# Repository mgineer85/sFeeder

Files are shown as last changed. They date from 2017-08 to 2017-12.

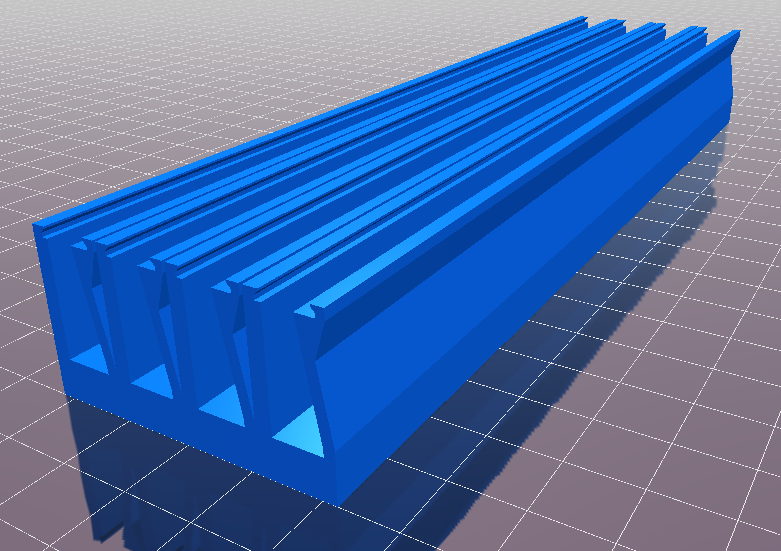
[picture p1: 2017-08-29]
parametric_feeder_example.png

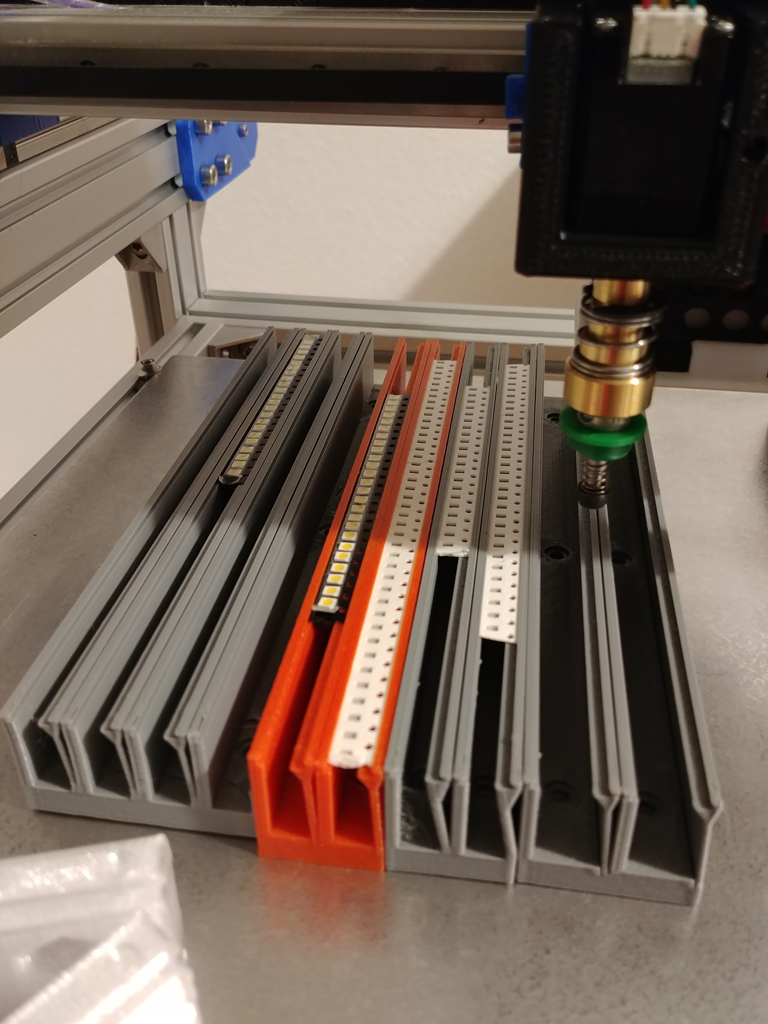
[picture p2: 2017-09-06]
parametric_feeder_photo.jpg

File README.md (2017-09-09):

# Parametric SMT Tape Feeder
=====

What is it for?
---
Serves to hold SMT tapes with resistors, capacitors, etc. in place. Designed to use in a Pick and Place Machine, like [OpenPnP](http://openpnp.org/). Another option would be [this](http://malte-randt.de/strip-feeders-and-modular-tray-for-smd/).

Features
---
  * parametric design fully adaptable to your needs
  * width of one feeder is tapeWidth + 3mm, eg. for 8mm tapes the feeder will be 11mm 
  * gang multiple feeder in one element
  * fully 3d printable, optimized design for best print results
  * keeps tape in position by slight force causing friction
  * no vitamins needed
  * prepared to be mounted to bed by 6mmx3mm magnets or M3 screw
  * try in Thingiverse Customizer

https://www.thingiverse.com/thing:2506053

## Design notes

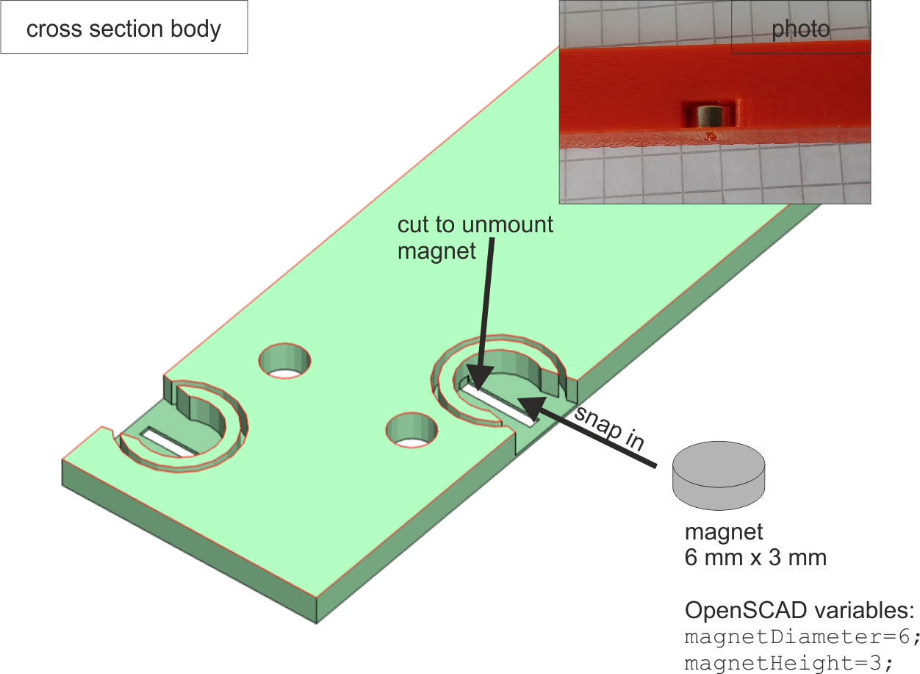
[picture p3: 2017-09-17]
sFeederOpenSCAD_magnetPockets.png

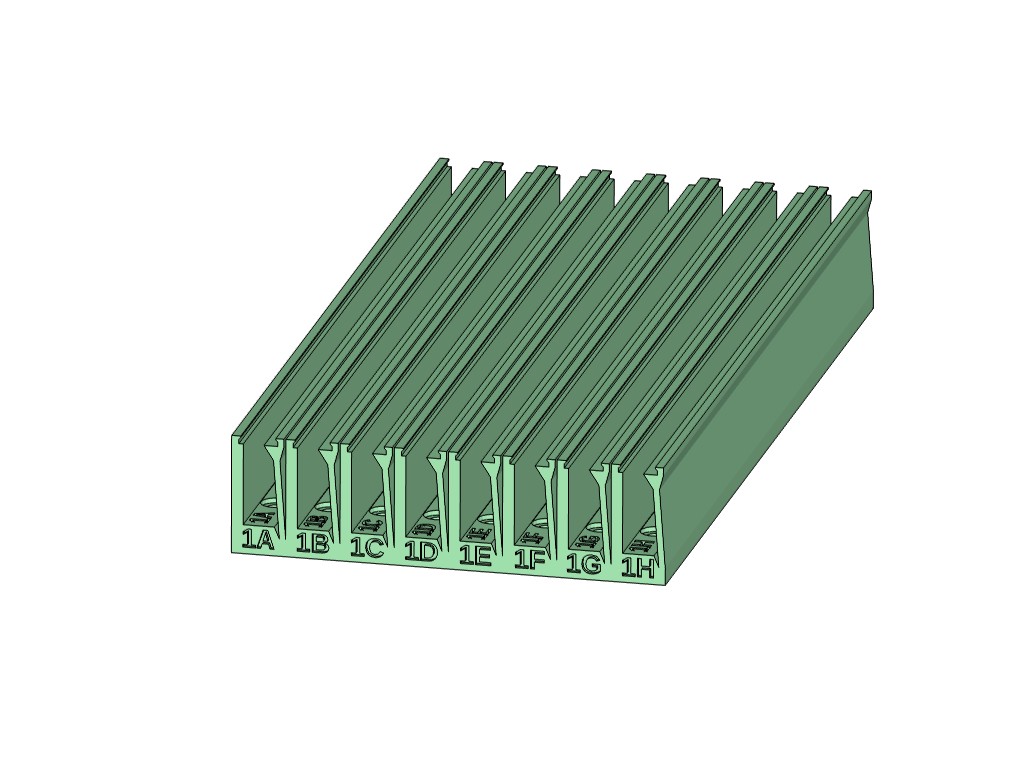
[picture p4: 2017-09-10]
gangedFeeder8mm with Identifier.jpg

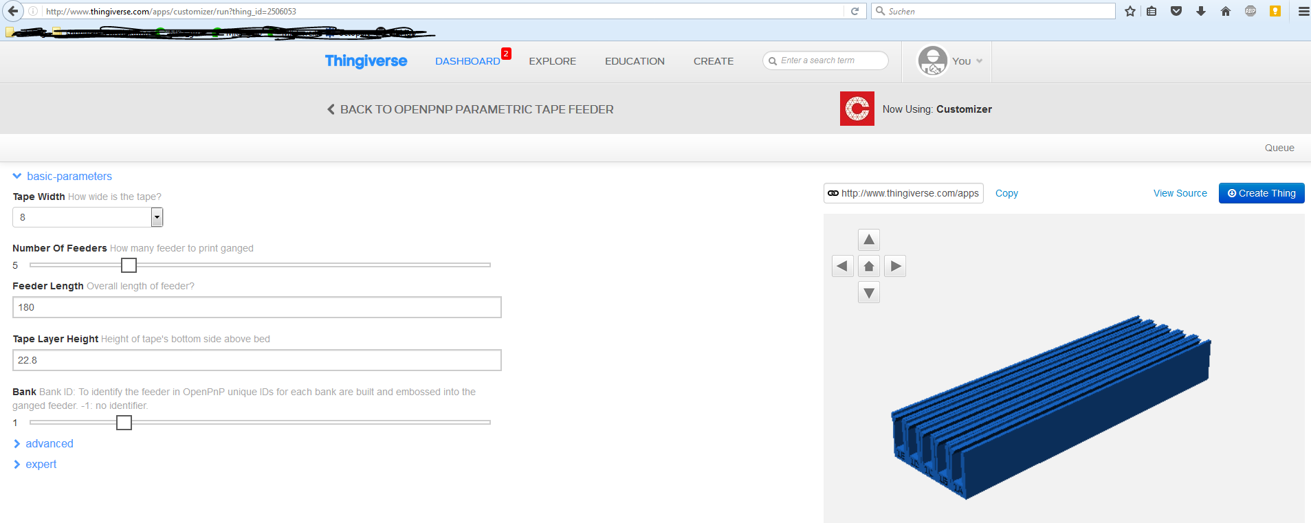
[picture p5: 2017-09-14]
screenshot_customizer.PNG

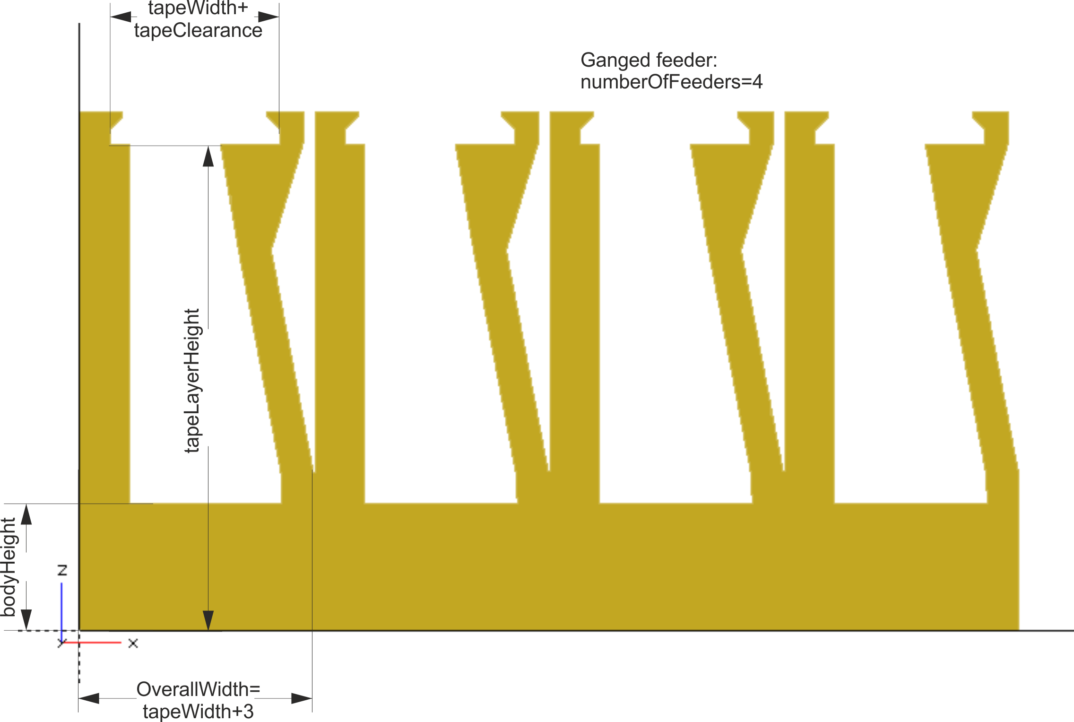
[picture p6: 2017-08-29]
parametric_feeder_desc.png

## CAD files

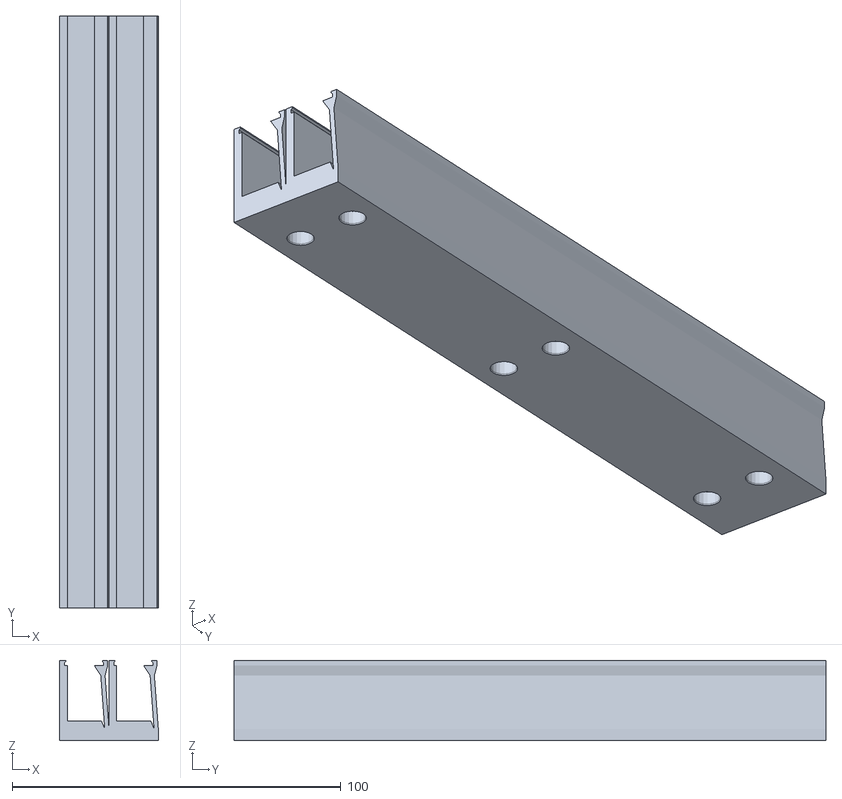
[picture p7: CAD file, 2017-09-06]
sFeeder_12mm_2feeders_180mm_22.8mm.stl
30.0 x 180.0 x 24.4

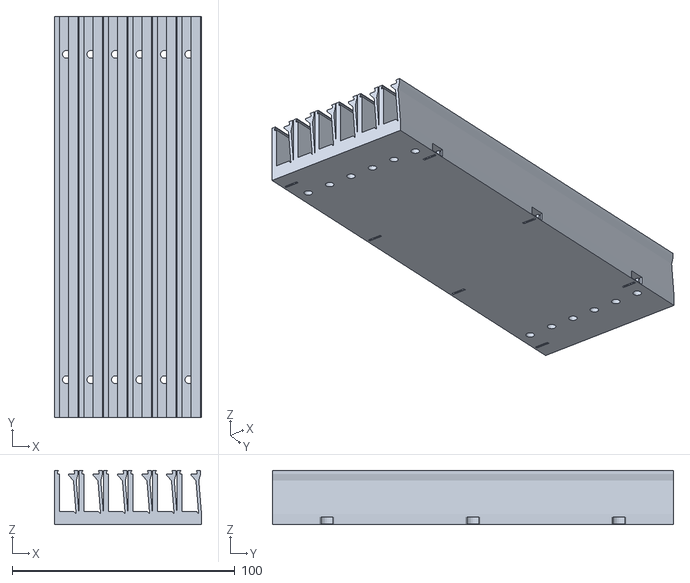
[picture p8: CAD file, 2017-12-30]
stl/sFeeder_8mm_6ganged.stl
66.0 x 180.0 x 24.4

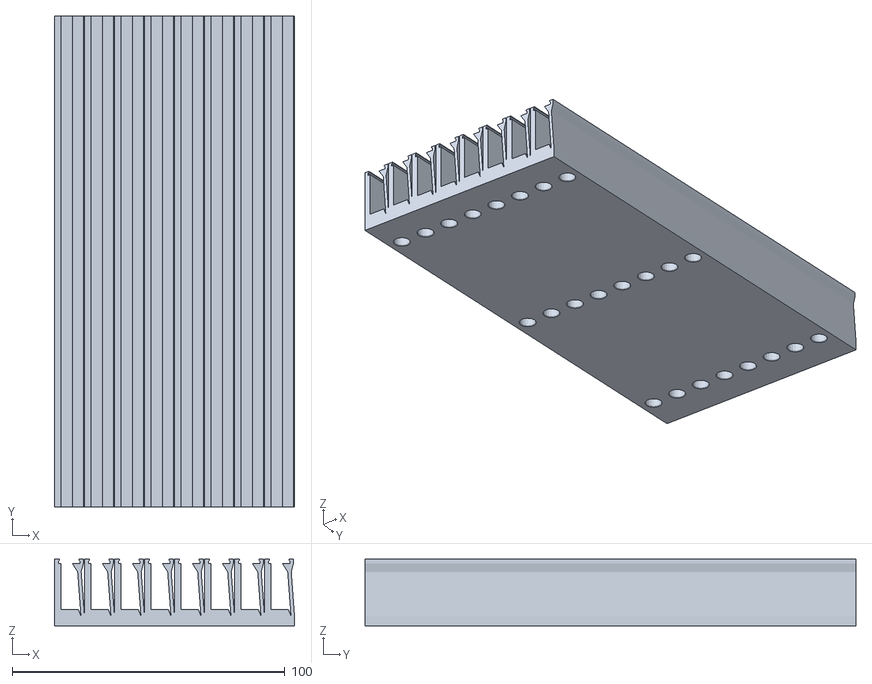
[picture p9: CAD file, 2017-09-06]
sFeeder_8mm_8feeders_180mm_22.8mm.stl
88.0 x 180.0 x 24.4

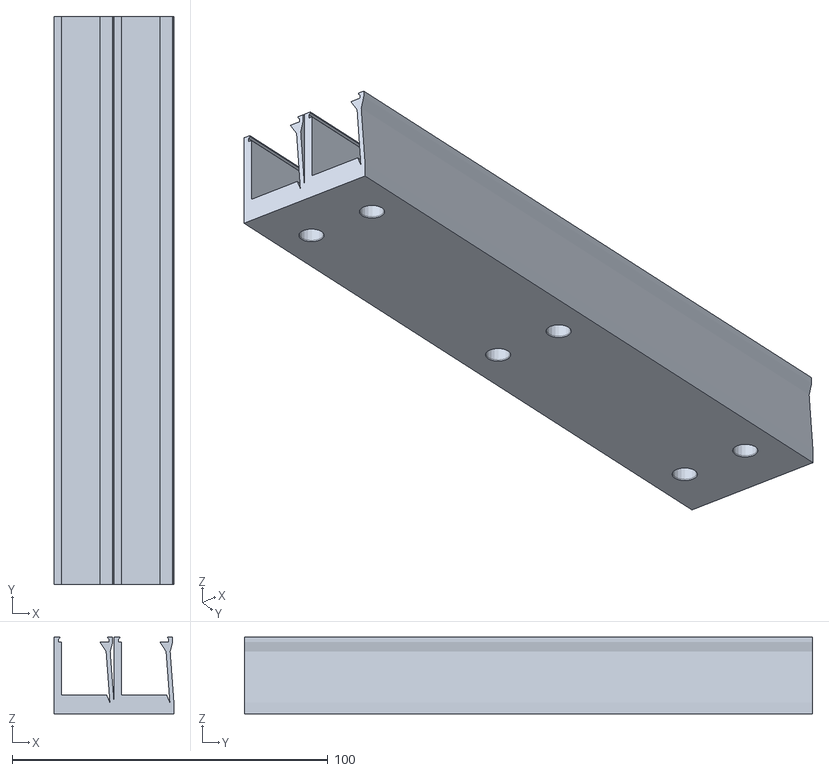
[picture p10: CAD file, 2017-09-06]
sFeeder_16mm_2feeders_180mm_22.8mm.stl
38.0 x 180.0 x 24.4

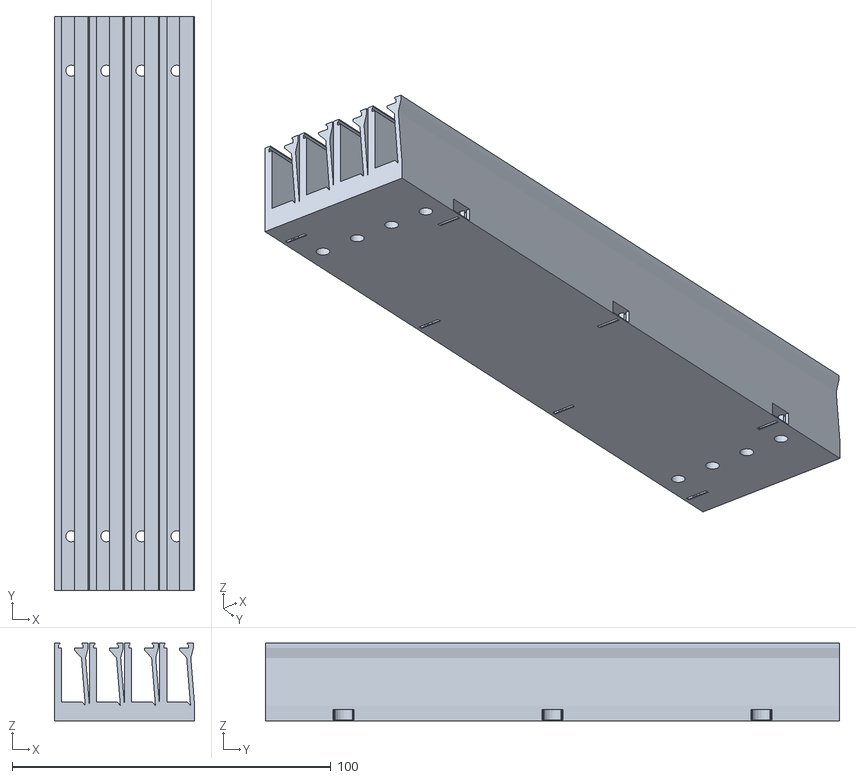
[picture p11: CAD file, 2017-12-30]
stl/sFeeder_8mm_4ganged.stl
44.0 x 180.0 x 24.4

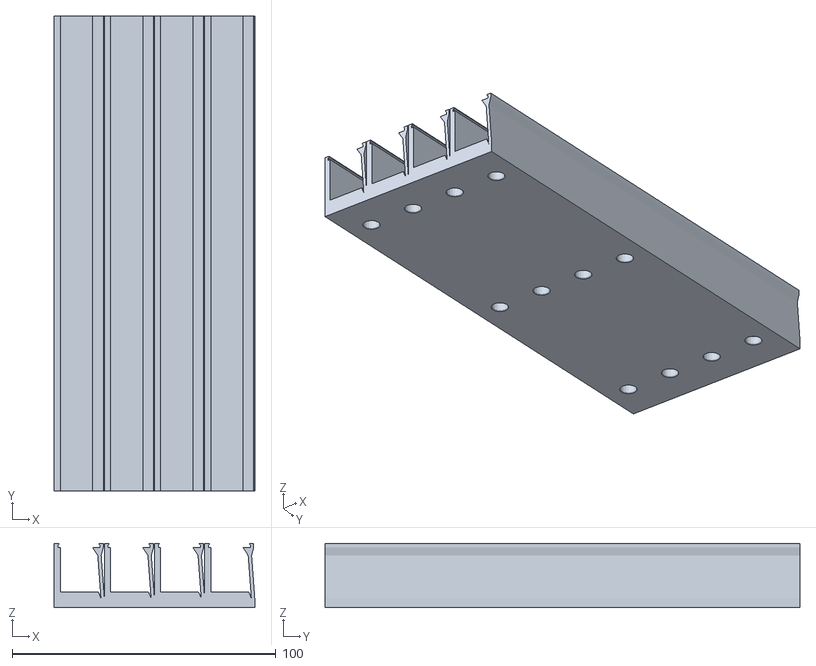
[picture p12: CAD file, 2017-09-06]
sFeeder_16mm_4feeders_180mm_22.8mm.stl
76.0 x 180.0 x 24.4

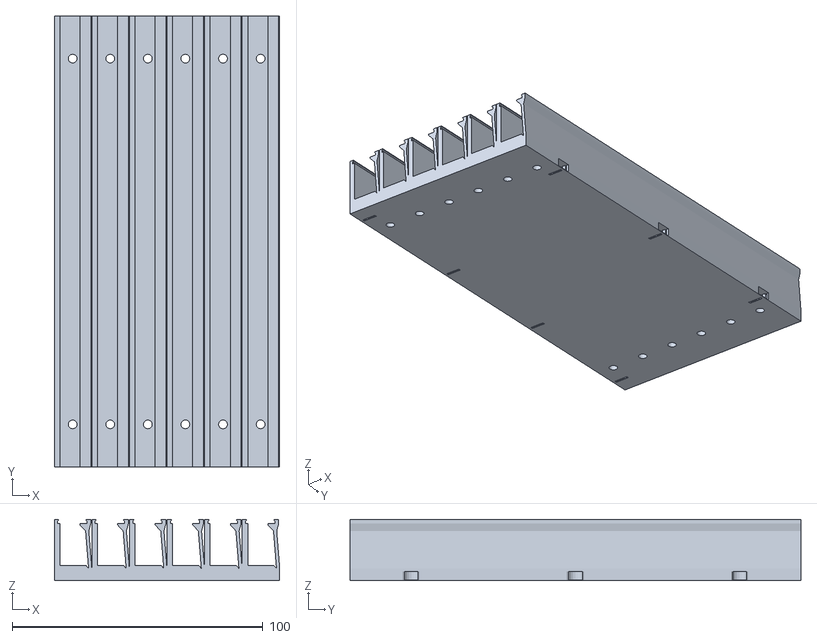
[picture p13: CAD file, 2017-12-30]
stl/sFeeder_12mm_6ganged.stl
90.0 x 180.0 x 24.4

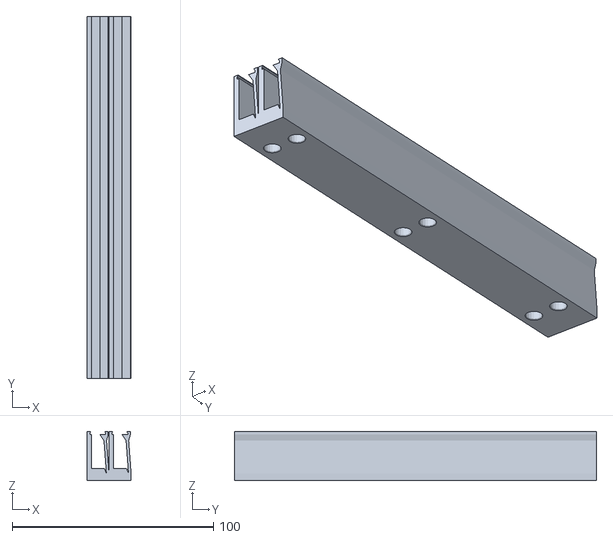
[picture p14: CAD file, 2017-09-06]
sFeeder_8mm_2feeders_180mm_22.8mm.stl
22.0 x 180.0 x 24.4

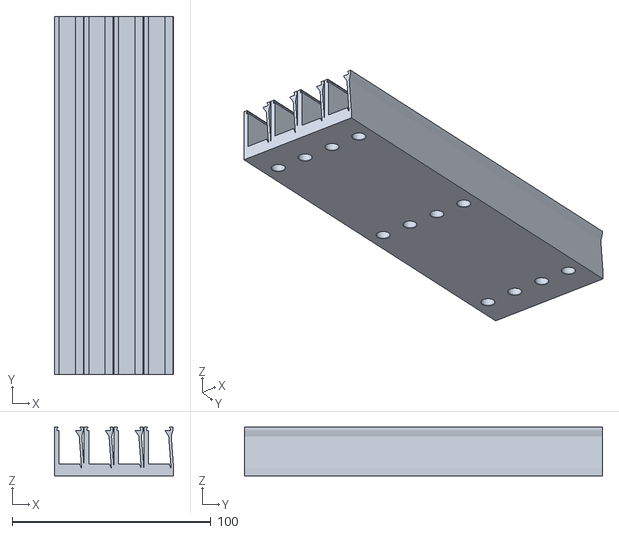
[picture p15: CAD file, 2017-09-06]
sFeeder_12mm_4feeders_180mm_22.8mm.stl
60.0 x 180.0 x 24.4

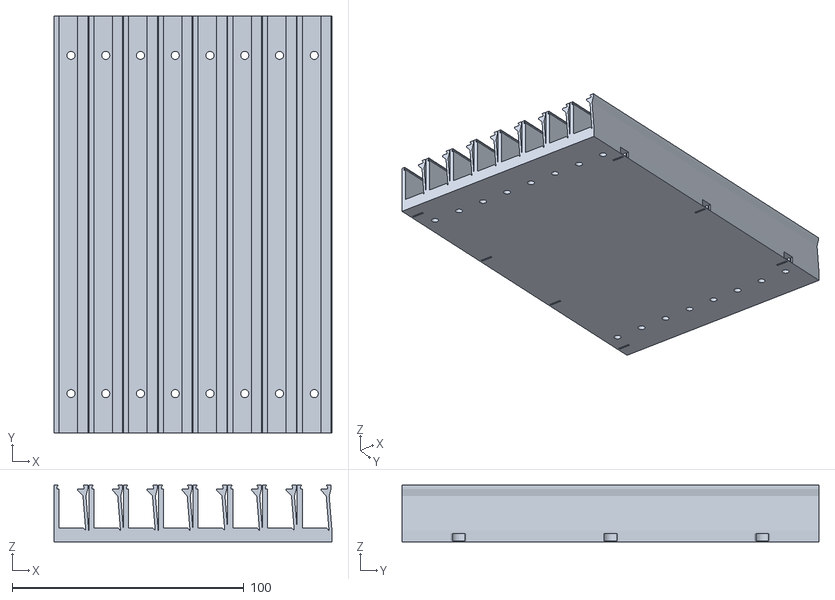
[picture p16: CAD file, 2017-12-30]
stl/sFeeder_12mm_8ganged.stl
120.0 x 180.0 x 24.4

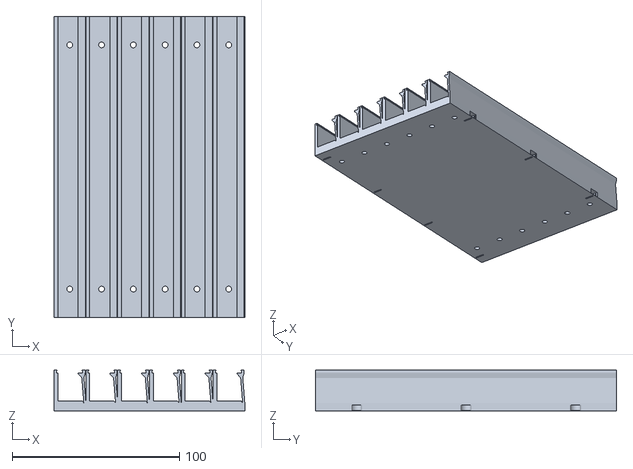
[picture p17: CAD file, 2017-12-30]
stl/sFeeder_16mm_6ganged.stl
114.0 x 180.0 x 24.4

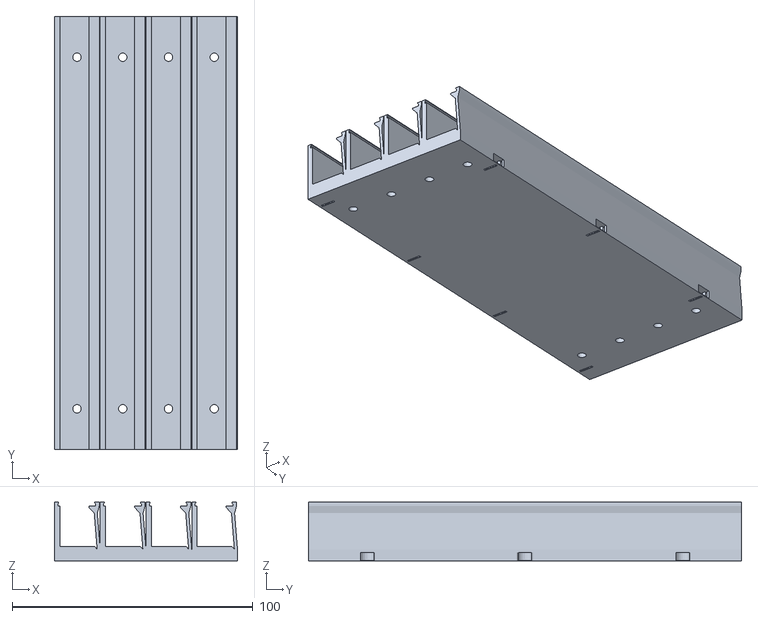
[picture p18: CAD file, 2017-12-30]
stl/sFeeder_16mm_4ganged.stl
76.0 x 180.0 x 24.4

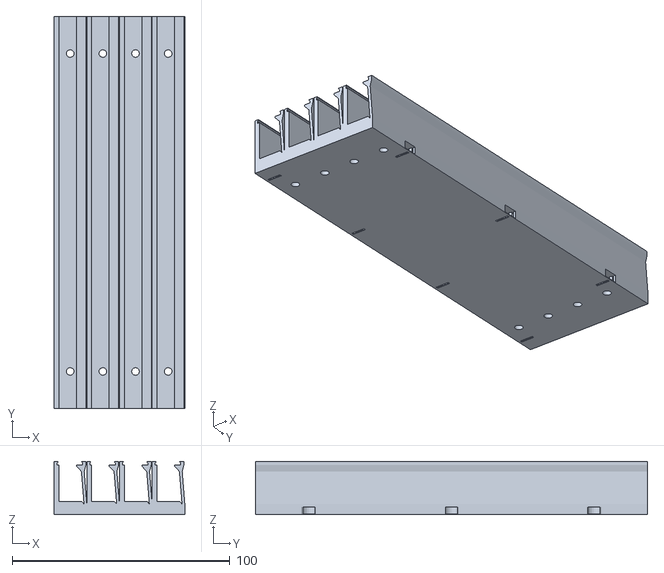
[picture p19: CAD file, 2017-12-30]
stl/sFeeder_12mm_4ganged.stl
60.0 x 180.0 x 24.4

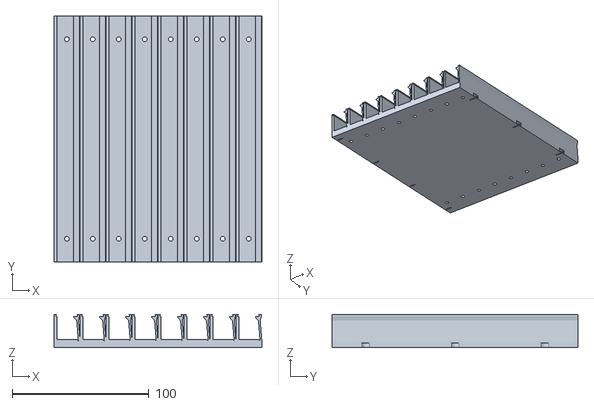
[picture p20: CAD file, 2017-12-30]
stl/sFeeder_16mm_8ganged.stl
152.0 x 180.0 x 24.4

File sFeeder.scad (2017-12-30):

/*
Author: Michael

2017/10/28

*/

/* [basic parameters] */

//How wide is the tape?
tapeWidth=8; // [8, 12, 16, 24, 36, 48, 72]
//Optimize for Plastic or Paper tape? Plastic tapes fit in Paper, but not reverse. Plastic tapes may be too loose in paper feeder.
tapeHeight=0.9; // [0.9:paper,0.3:plastic]
//How many feeder to print ganged
numberOfFeeders=2; // [1:1:20]
//Overall length of feeder?
feederLength=180;
//Height of tape's bottom side above bed
tapeLayerHeight=22.8;
//Bank ID: To identify the feeder in OpenPnP unique IDs for each bank are built and embossed into the ganged feeder. -1: no identifier.
bankID=1; //[-1:1:9]
//diameter of pockets on the side to put a magnet in
magnetDiameter=6;
//height of the pocket for the magnet
magnetHeight=3;

/* [advanced] */

//controls the force to keep the tape in place. lower value higher force and though friction
tapeClearance=-0.3;     // [-0.5:0.05:0.5]
bodyHeight=6;
tapeSupportHoleSide=2.8;
tapeSupportNonHoleSide=0.9;



/* [expert] */
//higher values make the left arm stronger
additionalWidth=3;
topFinishingLayer=0.3;
tapeGuideUpperOverhang=0.4;
//lower values make the spring smaller thus less force on tape, should be slightly less than a multiple of extrusion-width
springWidth=1.3;
springSkew=1.2;
//if two tapeloaded lanes touch each other raise this value a little
springClearance=0.4;

overallWidth=tapeWidth+additionalWidth;
overallHeight=tapeLayerHeight+tapeHeight+tapeGuideUpperOverhang+topFinishingLayer;
tapeXcenter=(overallWidth/2)+tapeClearance/2;

    

//make the feeders
gang_feeder();


// customizer specific stuff
// preview[view:north west, tilt:top diagonal]


module gang_feeder() {

    difference() {
        union() {

                
            //stack up feeders
            for(i=[0:1:numberOfFeeders-1]) {
                translate([i*(tapeWidth+additionalWidth),0,0]) 
                    feeder_body(i);
            }
            
            
        }
        
        //magnet pockets
        for(j=[0:1:2]) {
            //magnet pockets right side
            translate([0,j*((feederLength-49)/2)+24.5,0]) {
                translate([(numberOfFeeders)*(tapeWidth+additionalWidth),0,0 ]) {
                    magnetic_fixation_pocket(0,feederLength/2);
                }
            }
            
        }
        
        for(j=[0:1:3]) {
            translate([0,j*((feederLength-15)/3)+7.5,0]) {
                //magnet pockets left side
                rotate([0,0,180])
                    magnetic_fixation_pocket(0,feederLength/2);
            }
        }
    }
}

module feeder_cover() {
    cube([2,feederLength,overallHeight]);
}

module feeder_body(feederNo) {
    translate([0,feederLength,0]) {
        rotate([90,0,0]) {
            difference() {
                
                //main form
                linear_extrude(feederLength) {
                    polygon(points=[
                        //base
                        [0,0],
                        [overallWidth,0],
                    
                        //right arm way up ("spring", outer part)
                        [overallWidth,bodyHeight*0.8],
                        [overallWidth-springSkew,tapeLayerHeight-3],
                        [overallWidth-springClearance,tapeLayerHeight],
                    
                        //right arm tape guide
                        [overallWidth-springClearance,overallHeight],
                        [tapeXcenter+tapeWidth/2+tapeClearance-tapeGuideUpperOverhang,overallHeight],
                        [tapeXcenter+tapeWidth/2+tapeClearance-tapeGuideUpperOverhang,tapeLayerHeight+tapeHeight+tapeGuideUpperOverhang],
                        [tapeXcenter+tapeWidth/2+tapeClearance,tapeLayerHeight+tapeHeight],
                        [tapeXcenter+tapeWidth/2+tapeClearance,tapeLayerHeight],
                        [tapeXcenter+tapeWidth/2+tapeClearance-tapeSupportHoleSide,tapeLayerHeight],
                        [tapeXcenter+tapeWidth/2+tapeClearance-tapeSupportHoleSide,tapeLayerHeight-0.6],
                    
                        //right arm way down ("spring", inner part)
                        [overallWidth-springSkew-springWidth,tapeLayerHeight-3],
                        [overallWidth-springWidth,bodyHeight*0.8],
                        [overallWidth-springWidth-1,bodyHeight],
                        
                        //base (inner part)
                        [tapeXcenter-tapeWidth/2+tapeSupportNonHoleSide,bodyHeight],
                        
                        //left arm up (inner part)
                        [tapeXcenter-tapeWidth/2+tapeSupportNonHoleSide,tapeLayerHeight],
                        
                        //left arm tape guide
                        [tapeXcenter-tapeWidth/2,tapeLayerHeight],
                        [tapeXcenter-tapeWidth/2,tapeLayerHeight+tapeHeight],
                        [tapeXcenter-tapeWidth/2+tapeGuideUpperOverhang,tapeLayerHeight+tapeHeight+tapeGuideUpperOverhang],
                        [tapeXcenter-tapeWidth/2+tapeGuideUpperOverhang,overallHeight],
                        
                        //left arm down (outer part)
                        [0,overallHeight],
                        [0,0]

                    ]);
                }
                
                //direction of travel while picking with OpenPnP
                if(feederLength>=100) {
                    for (i=[0:1:3]) {
                        translate([additionalWidth+3/2+0.5,bodyHeight+0.1,feederLength-25-(i*6)])
                            rotate([90,90,0])
                                linear_extrude(1)
                                    circle(3,$fn=3);
                    }
                }
                
                //4 identification marks
                translate([additionalWidth,bodyHeight-0.9,feederLength-2])
                    rotate([90,90,180])
                        identification_mark(feederNo,"left","top");
                
                translate([additionalWidth,bodyHeight-0.9,2])
                    rotate([90,90,180])
                        identification_mark(feederNo,"right","top");
                
                translate([tapeXcenter,bodyHeight-0.9,feederLength-0.9])
                    rotate([0,0,0])
                        identification_mark(feederNo,"center","top");
                
                translate([tapeXcenter,bodyHeight-0.9,0.9])
                    rotate([0,180,0])
                        identification_mark(feederNo,"center","top");
                
                //reference hole
                translate([tapeXcenter+tapeWidth/2+tapeClearance-1.75,tapeLayerHeight,feederLength-4])
                    rotate([90,90,0])
                        cylinder(h=0.6,d=1.4,center=false,$fn=20);
                
                //3 registration points (for magnets, bolts or to screw from top)
                //bottom_fixation(feederLength/2);
                bottom_fixation(17);
                bottom_fixation(feederLength-17);
                

            }
        }
    }
}

module identification_mark(feederNo,_halign,_valign) {

    if(bankID!=-1) {
        linear_extrude(height=.91) {
            text( str(bankID, chr(feederNo+65) ),font=":style=Bold", size=4, valign=_valign, halign=_halign);
        }
    }
                
}
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

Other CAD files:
stl/sFeeder_12mm_2ganged.stl
stl/sFeeder_8mm_8ganged.stl
stl/sFeeder_8mm_2ganged.stl
stl/sFeeder_16mm_2ganged.stl

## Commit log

2017-08-29 slightly less strength of spring
    [sFeeder.scad, sFeeder_8mm_2feeders_180mm_22.8mm.stl, sFeeder_8mm_4feeders_180mm_22.8mm.stl]
2017-08-29 less spring force
    [sFeeder.scad, sFeeder_8mm_2feeders_180mm_22.8mm.stl, sFeeder_8mm_4feeders_180mm_22.8mm.stl]
2017-09-06 +spring lengthened to have less friction +raised tapeHeightClearance from 0.6 to 0.9 +springWidth slightly less
    [sFeeder.scad]
2017-09-06 updated STLs
    [sFeeder_12mm_2feeders_180mm_22.8mm.stl, sFeeder_8mm_2feeders_180mm_22.8mm.stl, sFeeder_8mm_4feeders_180mm_22.8mm.stl]
2017-09-06 +chamfer to get magnets mounted easier +thicker spring +more stls
    [sFeeder.scad, sFeeder_12mm_2feeders_180mm_22.8mm.stl, sFeeder_12mm_4feeders_180mm_22.8mm.stl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]
2017-09-09 +identifier to help organizing in OpenPnP
    [sFeeder.scad]
2017-09-09 +README.md +fix to make lane identifier work in thingiverse customizer +updated stls +batch export file for windows (openpnp must be in environment path)
    [sFeeder.scad, sFeeder_12mm_2ganged.stl, sFeeder_12mm_4ganged.stl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]
2017-09-10 +cad model render +arrows to indicate the direction of travel while feeding
    [sFeeder.scad]
2017-09-14 added a reference hole for easier positioning another tape
    [sFeeder.scad]
2017-09-17 +magnet pockets
    [sFeeder.scad]
2017-09-17 +updated stls +image
    [sFeeder_12mm_2ganged.stl, sFeeder_12mm_4ganged.stl, sFeeder_12mm_6ganged.stl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]
2017-10-28 slightly more pressure on tape to hold it better hopefully less parts popping out. but if height is set properly that is no problem, just to make it more tolerant...
    [sFeeder.scad]
2017-12-30 added customizer option for plastic tape (paper is default because paper feeder can handle plastic tapes, too).
    [sFeeder.scad, sFeeder_12mm_2ganged.stl, sFeeder_12mm_4ganged.stl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]
